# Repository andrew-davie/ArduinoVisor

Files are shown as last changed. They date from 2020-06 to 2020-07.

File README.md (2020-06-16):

# ArduinoVisor

Project/source files for Arduino Mechanical TV
Using ATMEGA32U4 processor (Arduino Micro)

For build log and instructions, see
https://www.taswegian.com/NBTV/forum/viewforum.php?f=28

Files are setup for Visual Studio Code project with PlatformIO installed.
Authors: Andrew Davie, Keith Colson

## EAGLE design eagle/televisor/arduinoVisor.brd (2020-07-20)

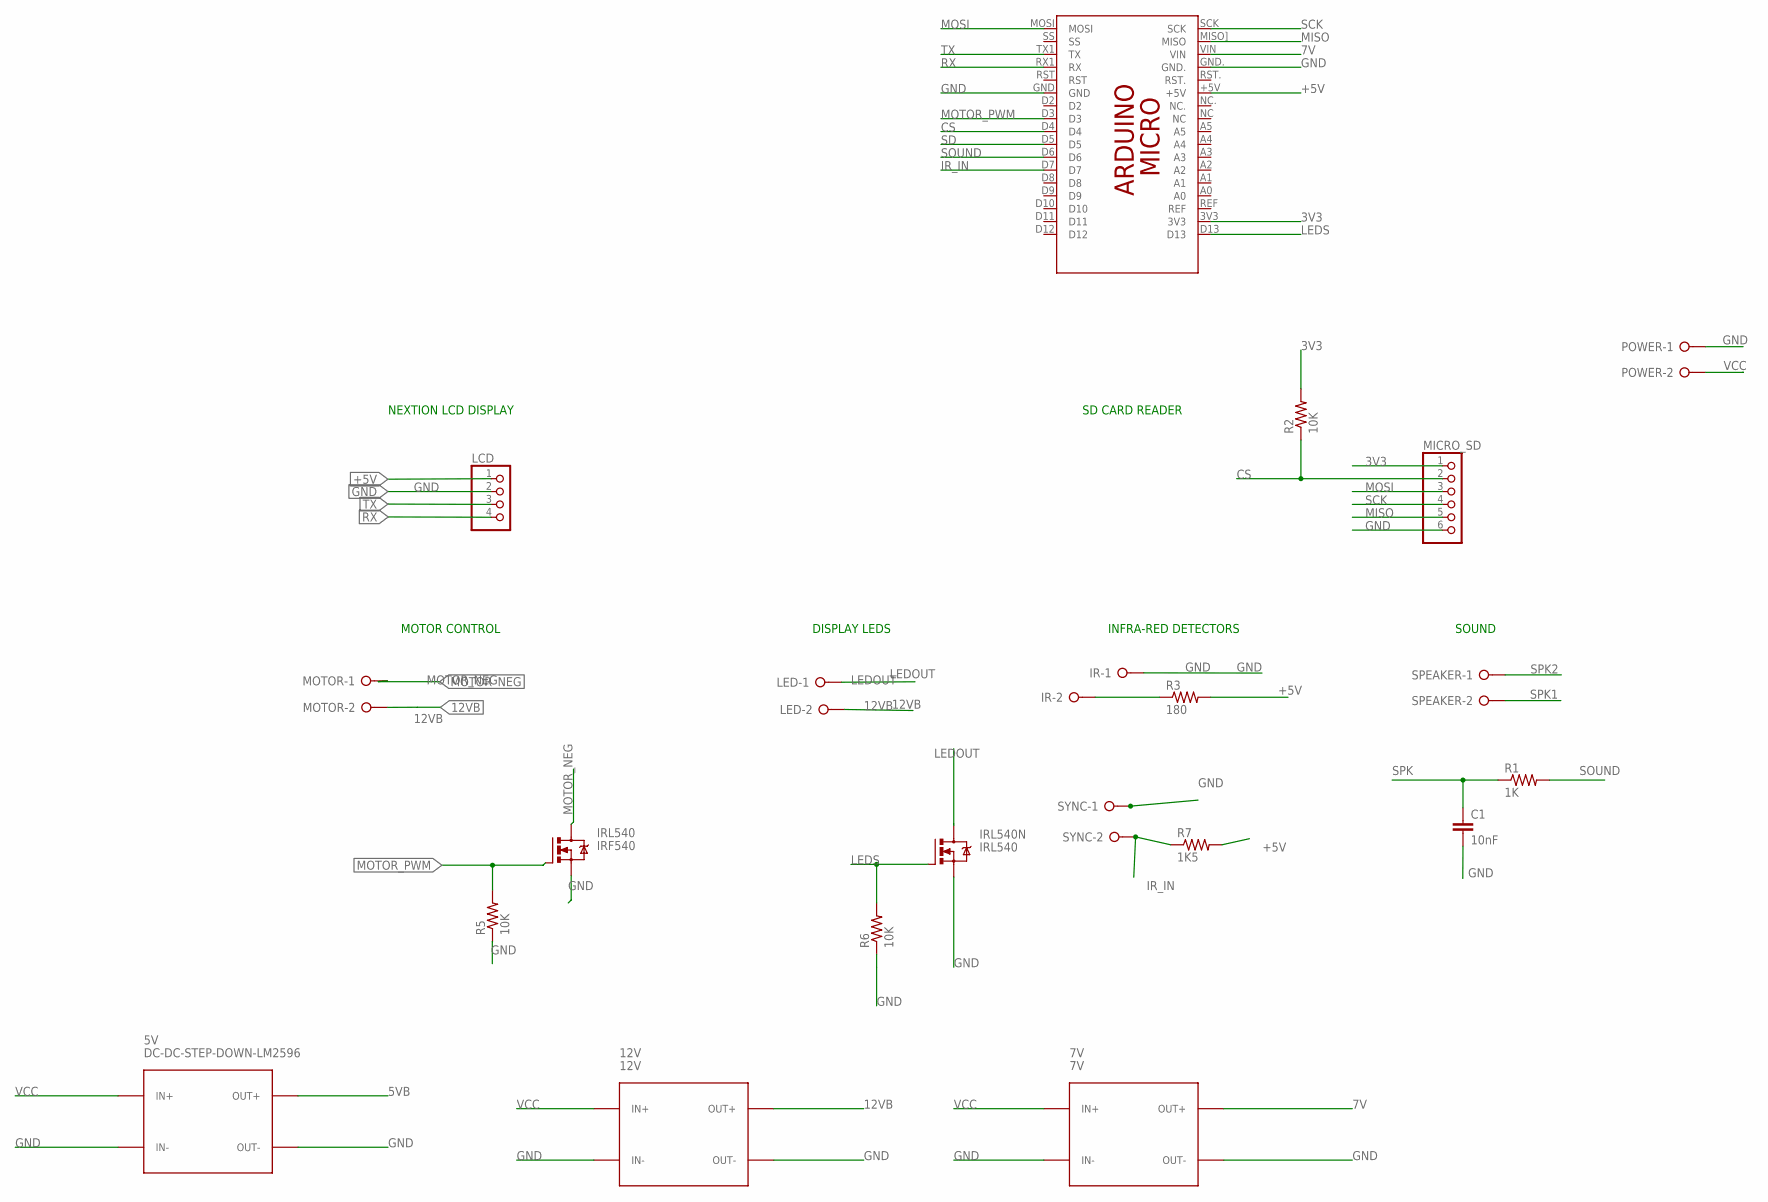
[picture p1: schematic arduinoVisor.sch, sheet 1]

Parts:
5V: DC-DC-STEP-DOWN-LM2596
7V: 7V; DC-DC-STEP-DOWN-LM2596
12V: 12V; DC-DC-STEP-DOWN-LM2596
C1: 10nF; C2.5-2
IR: W237-02P; W237-132
IRL540: IRF540; TO220BV
IRL540N: IRL540; TO220BV
LCD: PINHD-1X4; 1X04
LED: W237-02P; W237-132
MICRO_SD: PINHD-1X6; 1X06
MOTOR: W237-02P; W237-132
PCB2: ARDUINO_MICRO
POWER: W237-02P; W237-132
R1: 1K; 0207/10
R2, R5, R6: 10K; 0207/10
R3: 180; 0207/10
R7: 1K5; 0207/10
SPEAKER: W237-02P; W237-132
SYNC: W237-02P; W237-132

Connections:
3V3: MICRO_SD.1, PCB2.3V3, R2.2
5VB: 5V.OUT+; also elsewhere on the board
7V: 7V.OUT+, PCB2.VIN
12VB: 12V.OUT+, LED.2, MOTOR.2
+5V: LCD.1, PCB2.+5V, R3.2, R7.2
CS: MICRO_SD.2, PCB2.D4, R2.1
GND: 5V.IN-, 5V.OUT-, 7V.IN-, 7V.OUT-, 12V.IN-, 12V.OUT-, C1.2, IR.1, IRL540.S, IRL540N.S, LCD.2, MICRO_SD.6, PCB2.GND, PCB2.GND., POWER.1, R5.1, R6.1, SYNC.1; also elsewhere on the board
IR_IN: PCB2.D7, R7.1, SYNC.2
IR_OUT: IR.2, R3.1
LEDOUT: IRL540N.D, LED.1
LEDS: IRL540N.G, PCB2.D13, R6.2
MISO: MICRO_SD.5, PCB2.MISO] (MISO)
MOSI: MICRO_SD.3, PCB2.MOSI
MOTOR_NEG: IRL540.D, MOTOR.1
MOTOR_PWM: IRL540.G, PCB2.D3, R5.2
RX: LCD.4, PCB2.RX1 (RX)
SCK: MICRO_SD.4, PCB2.SCK
SD: PCB2.D5; also elsewhere on the board
SOUND: PCB2.D6, R1.2
SPK: C1.1, R1.1; also elsewhere on the board
SPK1: SPEAKER.2; also elsewhere on the board
SPK2: SPEAKER.1; also elsewhere on the board
TX: LCD.3, PCB2.TX1 (TX)
VCC: 5V.IN+, 7V.IN+, 12V.IN+, POWER.2

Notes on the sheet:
MOTOR CONTROL
DISPLAY LEDS
INFRA-RED DETECTORS
NEXTION LCD DISPLAY
SD CARD READER
SOUND

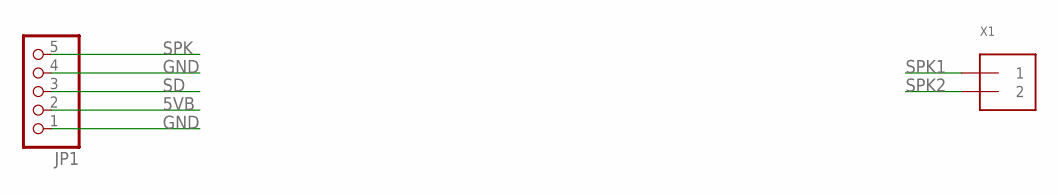
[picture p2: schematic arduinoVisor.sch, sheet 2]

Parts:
JP1: HEADER-1X570MIL; 1X05_ROUND_70
X1: TERMBLOCK_1X2; TERMBLOCK_1X2-3.5MM

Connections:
5VB: JP1.2; also elsewhere on the board
GND: JP1.1, JP1.4; also elsewhere on the board
SD: JP1.3; also elsewhere on the board
SPK: JP1.5; also elsewhere on the board
SPK1: X1.1; also elsewhere on the board
SPK2: X1.2; also elsewhere on the board

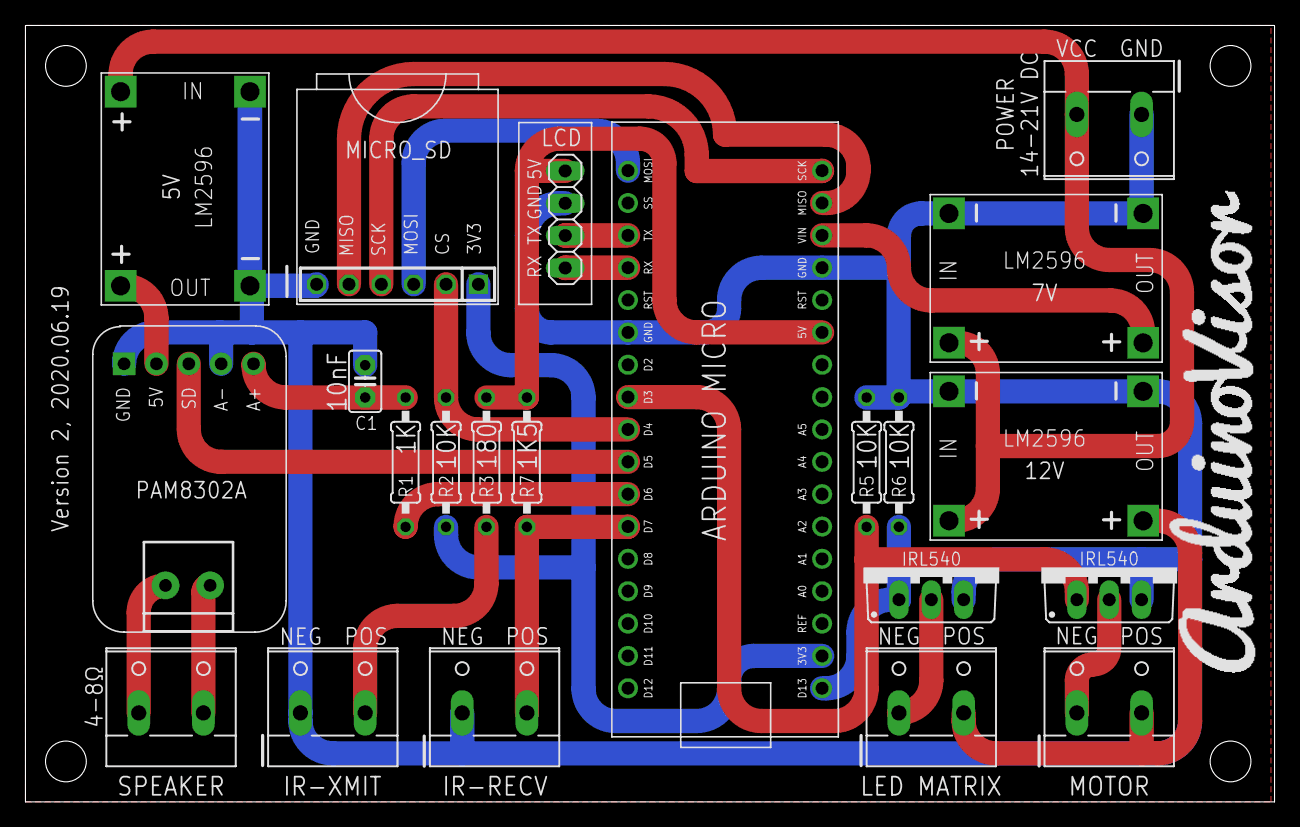
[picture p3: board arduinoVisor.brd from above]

Board: 2 copper layers, 98.1 x 61.0 mm, 23 parts (0 on the bottom side), 24 nets.

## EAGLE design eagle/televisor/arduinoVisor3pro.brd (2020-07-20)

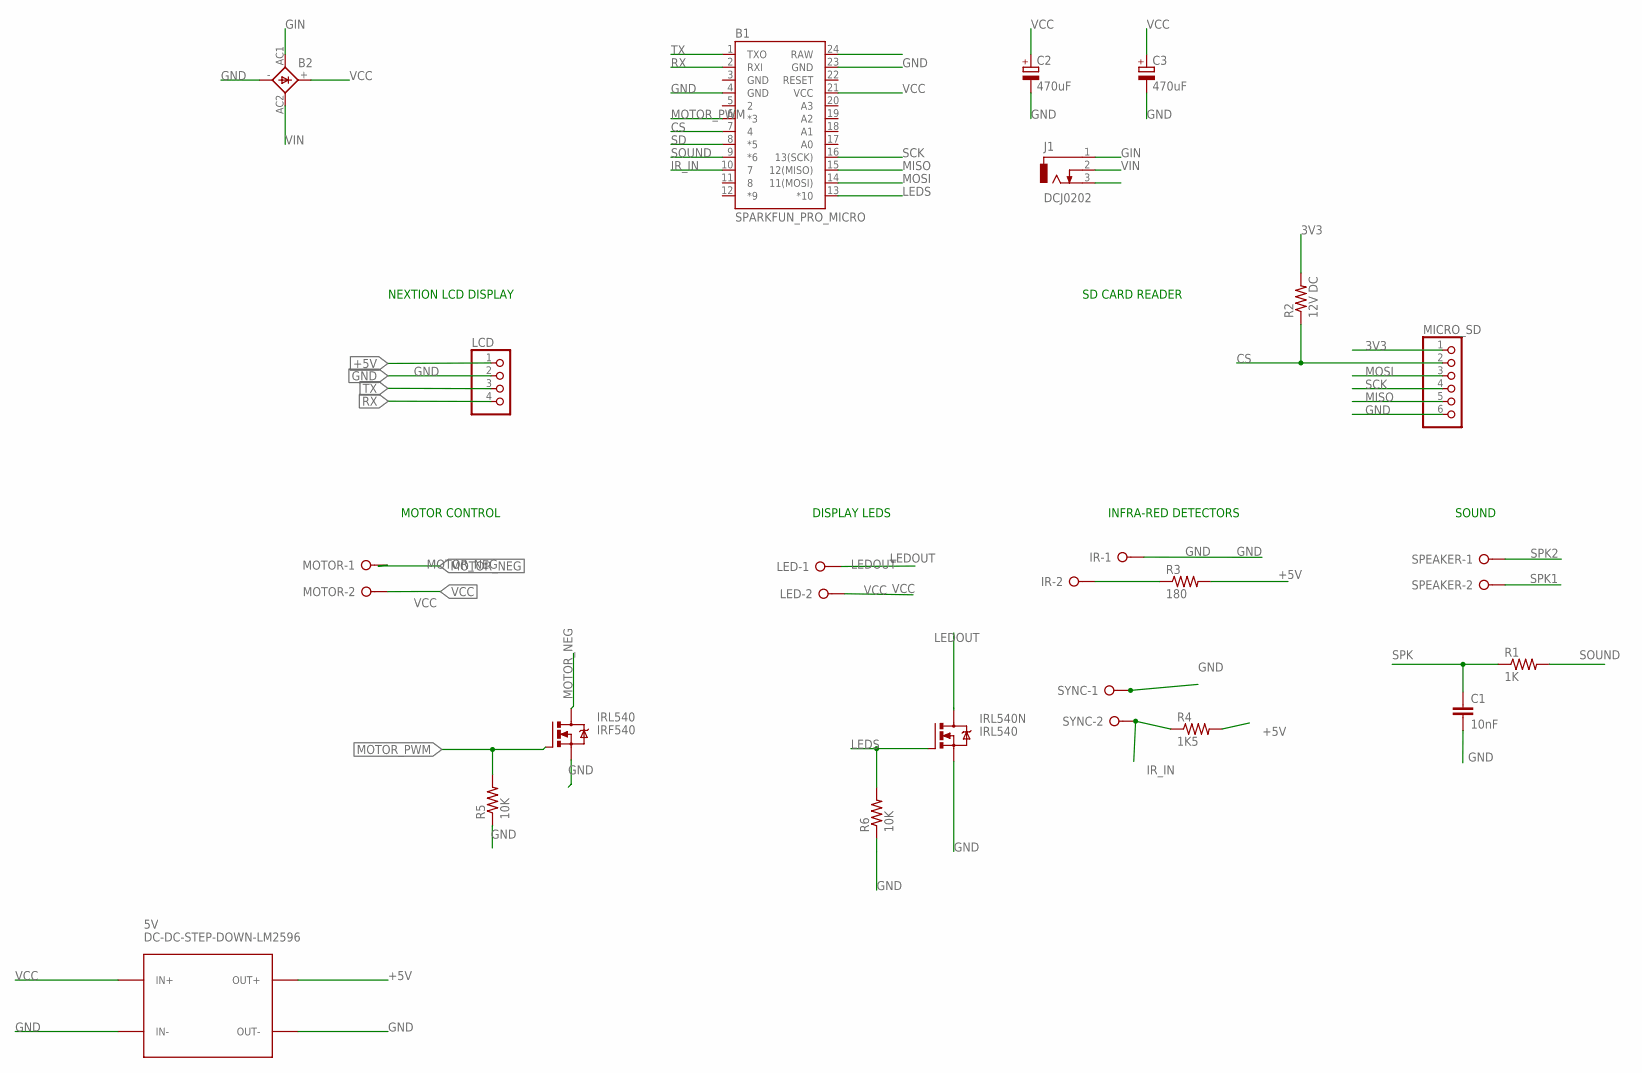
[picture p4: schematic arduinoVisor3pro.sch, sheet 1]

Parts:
5V: DC-DC-STEP-DOWN-LM2596
B1: SPARKFUN_PRO_MICRO
B2: 1KAB
C1: 10nF; C2.5-2
C2, C3: 470uF; E5-6
IR: W237-02P; W237-132
IRL540: IRF540; TO220BV
IRL540N: IRL540; TO220BV
J1: DCJ0202
LCD: PINHD-1X4; 1X04
LED: W237-02P; W237-132
MICRO_SD: PINHD-1X6; 1X06
MOTOR: W237-02P; W237-132
R1: 1K; 0207/10
R2: 12V DC; 0207/10
R3: 180; 0207/10
R4: 1K5; 0207/10
R5, R6: 10K; 0207/10
SPEAKER: W237-02P; W237-132
SYNC: W237-02P; W237-132

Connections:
3V3: MICRO_SD.1, R2.2
+5V: 5V.OUT+, B1.24 (RAW), LCD.1, R3.2, R4.2; also elsewhere on the board
CS: B1.7 (4), MICRO_SD.2, R2.1
GIN: B2.AC1, J1.1
GND: 5V.IN-, 5V.OUT-, B1.3 (GND), B1.4 (GND), B1.23 (GND), B2.-, C1.2, C2.-, C3.-, IR.1, IRL540.S, IRL540N.S, LCD.2, MICRO_SD.6, R5.1, R6.1, SYNC.1; also elsewhere on the board
IR_IN: B1.10 (7), R4.1, SYNC.2
IR_OUT: IR.2, R3.1
LEDOUT: IRL540N.D, LED.1
LEDS: B1.13 (*10), IRL540N.G, R6.2
MISO: B1.15 (12(MISO)), MICRO_SD.5
MOSI: B1.14 (11(MOSI)), MICRO_SD.3
MOTOR_NEG: IRL540.D, MOTOR.1
MOTOR_PWM: B1.6 (*3), IRL540.G, R5.2
RX: B1.2 (RXI), LCD.4
SCK: B1.16 (13(SCK)), MICRO_SD.4
SD: B1.8 (*5); also elsewhere on the board
SOUND: B1.9 (*6), R1.2
SPK: C1.1, R1.1; also elsewhere on the board
SPK1: SPEAKER.2; also elsewhere on the board
SPK2: SPEAKER.1; also elsewhere on the board
TX: B1.1 (TXO), LCD.3
VCC: 5V.IN+, B1.21 (VCC), B2.+, C2.+, C3.+, LED.2, MOTOR.2
VIN: B2.AC2, J1.2

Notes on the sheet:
MOTOR CONTROL
DISPLAY LEDS
INFRA-RED DETECTORS
NEXTION LCD DISPLAY
SD CARD READER
SOUND

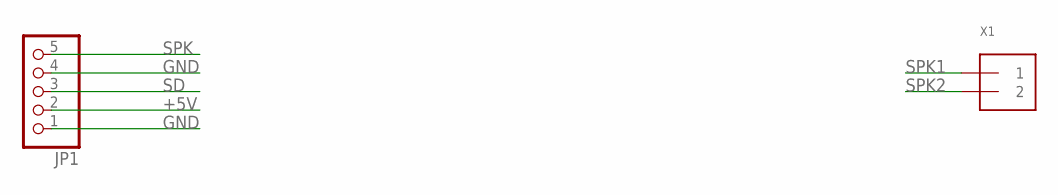
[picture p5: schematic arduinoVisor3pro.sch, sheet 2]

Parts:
JP1: HEADER-1X570MIL; 1X05_ROUND_70
X1: TERMBLOCK_1X2; TERMBLOCK_1X2-3.5MM

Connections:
+5V: JP1.2; also elsewhere on the board
GND: JP1.1, JP1.4; also elsewhere on the board
SD: JP1.3; also elsewhere on the board
SPK: JP1.5; also elsewhere on the board
SPK1: X1.1; also elsewhere on the board
SPK2: X1.2; also elsewhere on the board

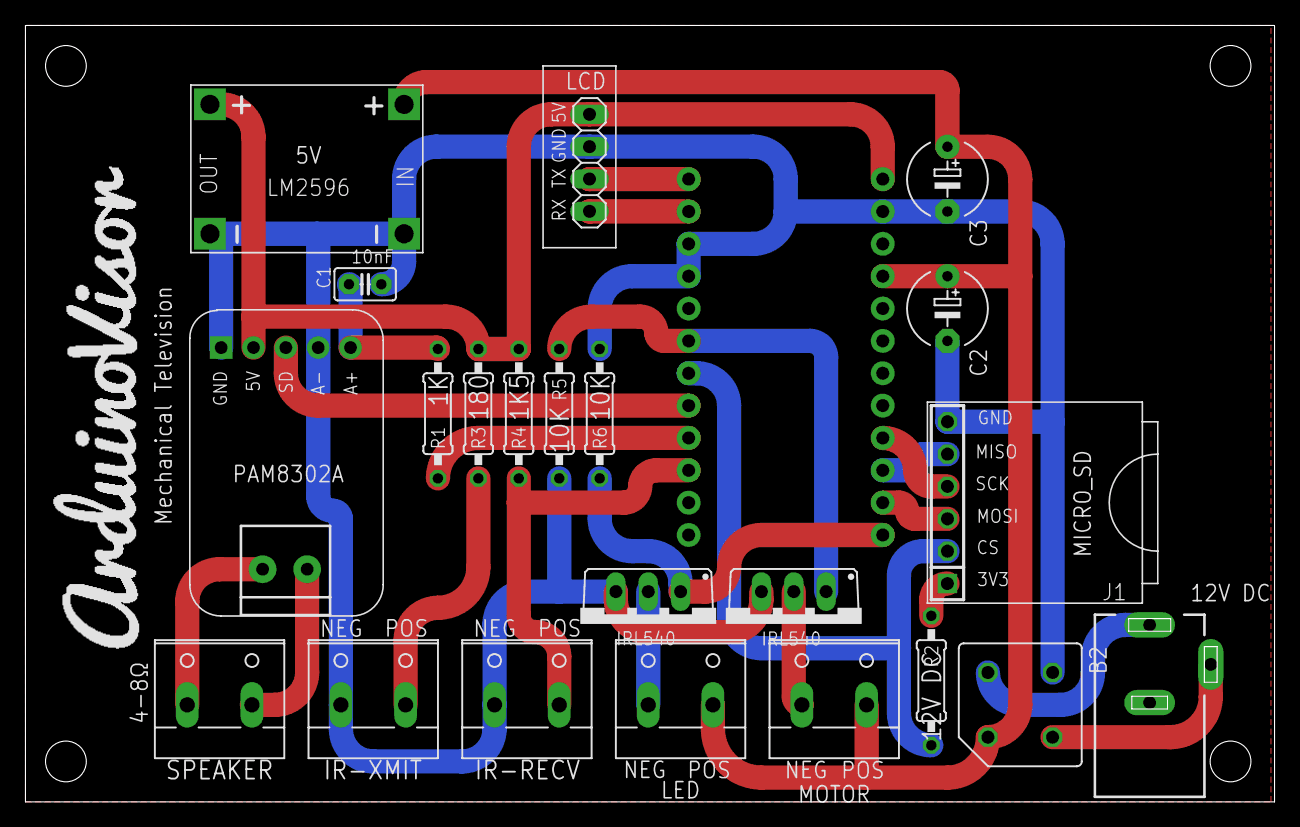
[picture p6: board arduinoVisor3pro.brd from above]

Board: 2 copper layers, 98.1 x 61.0 mm, 24 parts (0 on the bottom side), 23 nets.

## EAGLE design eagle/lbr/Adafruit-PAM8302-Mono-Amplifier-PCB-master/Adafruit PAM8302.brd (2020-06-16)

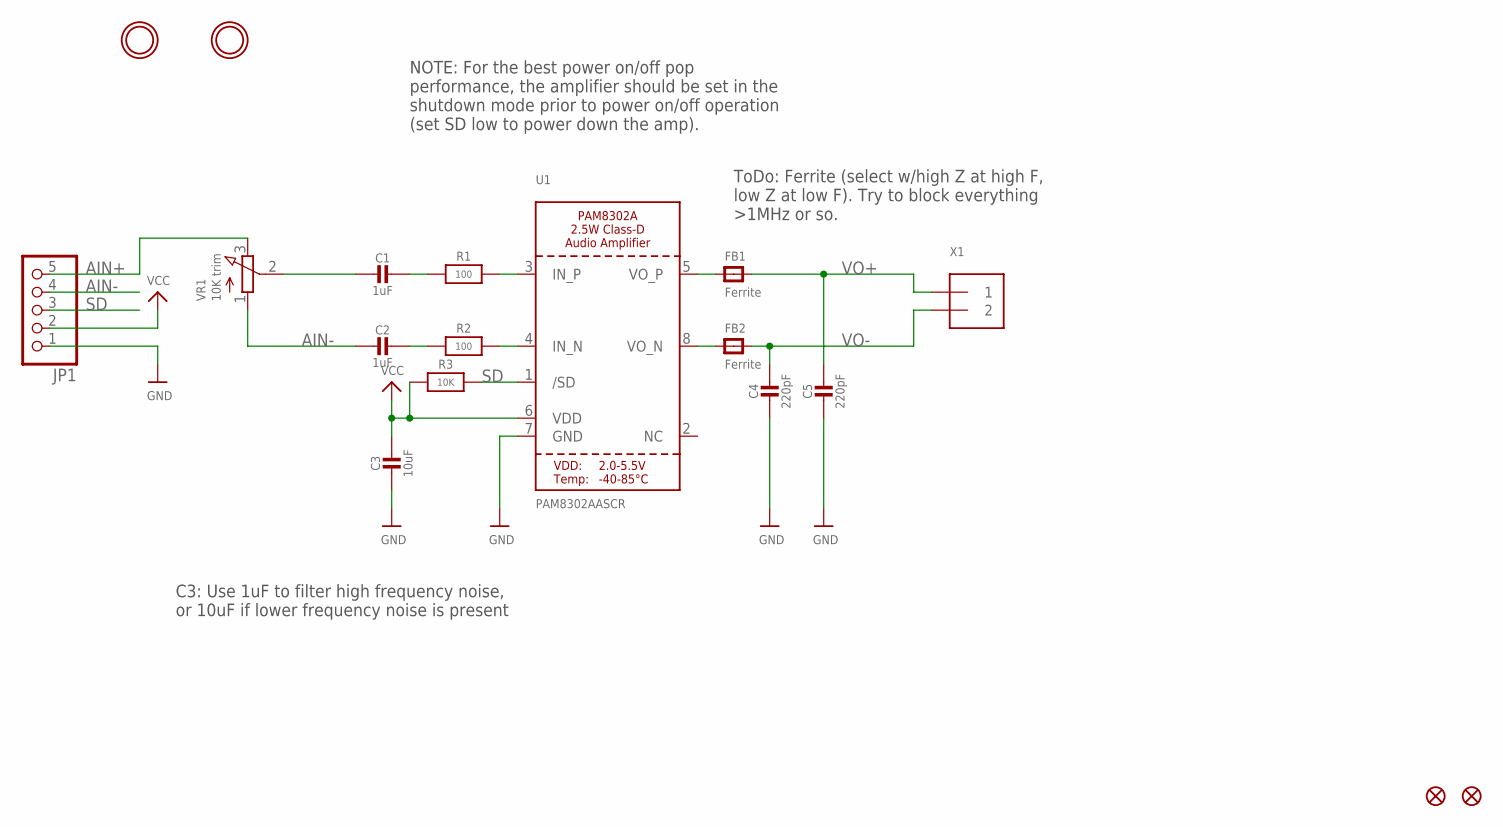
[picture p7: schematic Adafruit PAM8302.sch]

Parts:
C1, C2: 1uF; 0805-NO
C3: 10uF; 0805-NO
C4, C5: 220pF; 0805-NO
FB1, FB2: Ferrite; _0805
FID1, FID2: FIDUCIAL""; FIDUCIAL_1MM
JP1: HEADER-1X570MIL; 1X05_ROUND_70
R1, R2: 100; 0805-NO
R3: 10K; 0805-NO
U1: PAM8302AASCR; MSOP8_0.65MM
U$10, U$11: MOUNTINGHOLE2.0; MOUNTINGHOLE_2.0_PLATED
VR1: 10K trim; TRIMPOT_BOURNS_3303W
X1: TERMBLOCK_1X2; TERMBLOCK_1X2-3.5MM

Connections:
AIN+: JP1.5, VR1.3 (E)
AIN-: C2.2, JP1.4, VR1.1 (A)
GND: C3.2, C4.2, C5.2, JP1.1, U1.7 (GND)
unnamed: R2.2, U1.4 (IN_N)
unnamed: R1.2, U1.3 (IN_P)
unnamed: C1.1, R1.1
unnamed: C2.1, R2.1
unnamed: FB2.1, U1.8 (VO_N)
unnamed: FB1.1, U1.5 (VO_P)
unnamed: C1.2, VR1.2 (S)
SD: JP1.3, R3.2, U1.1 (/SD)
VCC: C3.1, JP1.2, R3.1, U1.6 (VDD)
VO+: C5.1, FB1.2, X1.1
VO-: C4.1, FB2.2, X1.2

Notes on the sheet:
ToDo: Ferrite (select w/high Z at high F, low Z at low F). Try to block everything >1MHz or so.
C3: Use 1uF to filter high frequency noise, or 10uF if lower frequency noise is present
NOTE: For the best power on/off pop performance, the amplifier should be set in the shutdown mode prior to power on/off operation (set SD low to power down the amp).

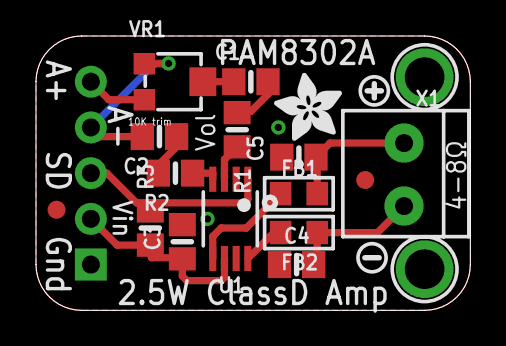
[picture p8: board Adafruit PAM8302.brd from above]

Board: 2 copper layers, 24.1 x 15.2 mm, 22 parts (1 on the bottom side), 14 nets.

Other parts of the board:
U$3: SYMBOL_PLUS
U$4: SYMBOL_MINUS
U$5: ADAFRUIT_3.5MM
U$6: PCBFEAT-REV-040

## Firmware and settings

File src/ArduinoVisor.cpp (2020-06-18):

////////////////////////////////////////////////////////////////////////////////////////////////////////////////////////////////
// Arduino Mechanical Televisor  https://github.com/andrew-davie/NBTV                                                         //
// This program implements all the functions needed for a working mechanical televisor using an a                             //
// Arduino Micro. For more information see https://www.taswegian.com/NBTV/forum/viewforum.php?f=28                            //
//                                                                                                                            //
// program by Andrew Davie (andrew@taswegian.com), March 2017...                                                              //
// and Keith Colson - http://www.edns.co.nz/index.php/about/ - September 2017...                                               //
//                                                                                                                            //
// Notes:                                                                                                                     //
// 1. Strings in the code actually use RAM.  To save RAM, use the macro F("string")                                           //
// 2. >>>> Debug mode is entered by sending a character on the console within two seconds of startup <<<<                     //
// 3. using 70% ram or more can make the upload fail, hold the reset button down and release when upload starts to fix it     //
//                                                                                                                            //
////////////////////////////////////////////////////////////////////////////////////////////////////////////////////////////////

#include <Arduino.h>
#include "televisor.h" // the main header file

void stopButtonCallback();

void fixVideoTable();

void fixAudioTable(uint8_t customVolume);

byte calculatePI(double speedErr, double frameErr);

// *************************** Nextion Library Support (touch screen) *********************************************************
#include "nexlite.h" // file to get rid of nextion library

///////////////////////////////////////////////////////////////////////////////////////////////////////////////////////////////
bool playing = false;
bool showInfo; // info txt file present
bool debug = false;
bool nextion = false; // assume no nextion connected until found
bool forceTimePreventSeeker;

uint8_t uiMode;        // = MODE_TITLE_INIT;     // program state
uint8_t selection = 0; // selected track # from menu
uint8_t baseVal;
uint32_t lastSeekPosition;

uint32_t shiftFrame = 80;

// *************************** Global Variables ***************************************************************

// PID variables
double integral;
double lastTime; // this is used to calculate delta time
double lastErr;  // this is used to calculate delta error
double motorSpeed;

File nbtv;
SdFat nbtvSD;

////////////////////////////////////////////////////////////////////////////////////////////////////////////////////////////////

uint8_t video[VIDEO_SIZE]; // convert sample to modified brightness/contrast/gamma/bit depth
uint8_t audio[AUDIO_SIZE]; // convert sample to modified audio/bit depth

int16_t customBrightness;
long customContrast2; // a X.Y fractional  (8 bit fractions) so 256 = 1.0f   and 512 = 2.0f

uint8_t customGamma; // flags if gamma should be applied

////////////////////////////////////////////////////////////////////////////////////////////////////////////////////////////////

uint32_t customRepeat = 0;

uint8_t countFiles(void);

void resetStream(long seeker);

void setupFastPwm(int mode);

void setupMotorPWM();

void qInit(char *name);

void drawTime(const char *name, int sec);

void composeMenuItem(int item, int s, char *p, bool hunt);

uint8_t circularAudioVideoBuffer[CIRCULAR_BUFFER_SIZE];

uint32_t playbackAbsolute;
uint32_t lastPlaybackAbsolute;
uint32_t dataPosition; // WAV file start of data chunk (for rewind/seek positioning)

uint8_t *pbp;

uint32_t videoLength;
uint32_t streamAbsolute;
uint16_t bufferOffset;
uint16_t sampleRate;
uint16_t singleFrame;
uint8_t bytesPerSample; // bytes per sample
uint32_t oneSecond;

unsigned long lastDetectedIR;

////////////////////////////////////////////////////////////////////////////////////////////////////////////////////////////////
void nl_Callback(struct nl_struct *ns)
{
    // event from nextion - nl means nextion lite - ns means nextion struct
    // Serial.print(ns->buff[1]);  Serial.print("  ,  "); Serial.print(ns->buff[2]); Serial.print("  ,  "); Serial.println(ns->buff[3]);//  Serial.println(ns->buff[4]);
    switch (ns->buff[0]) {
        // command type
        case NEX_RET_EVENT_TOUCH_HEAD: // touch happened       0x65 0x02 0x08 0x00 0xFF 0xFF 0xFF
            gotTouch(ns);          // call the touch parser
            break;

        case NEX_RET_NUMBER_HEAD: // get ?.val result     0x71 0x80 0x00 0x00 0x00 0xFF 0xFF 0xFF
            gotValue(ns);     // call the number parser
            break;

        case NEX_RET_CMD_FINISHED: // basically an ACK     0x01 0xFF 0xFF 0xFF
            break;             // nothing needed here
    }
}

void titleCallback();

void gotTouch(struct nl_struct *ns)
{

    switch (ns->buff[1]) {
        // page number

        case PAGE_STRT: // page 0 has touch
            titleCallback();
            break;

        case PAGE_MENU: // page 1 has touch
            switch (ns->buff[2]) {
                // id
                case H0_ID: // file slider touch
                    // nl_GetVal(H0_GET, H0_NAME);   // get file list slide value
                    nl_GetVal(BAS_GET, BAS_NAME); // get the base value (scroll position)
                    break;

                case FIL_ID:              // file selected
                    nl_GetVal(FIL_GET, FIL_NAME); // get file to open slide value
                    break;
            }

            break;

        case PAGE_PLAY: // page 2 has touch
            switch (ns->buff[2]) {
                // id
                case BRT_ID:              // brightness slider touch
                    nl_GetVal(BRT_GET, BRT_NAME); // get brightness slide value
                    break;

                case CON_ID:              // contrast slider touch
                    nl_GetVal(CON_GET, CON_NAME); // get contrast slide value
                    break;

                case VOL_ID:              // 0x71 0x80 0x00 0x00 0x00 0xFF 0xFF 0xFF
                    nl_GetVal(VOL_GET, VOL_NAME); // get volume slide value
                    break;

                case SEK_ID:              // seeker slider touch
                    nl_GetVal(SEK_GET, SEK_NAME); // get seeker slide value
                    break;

                case INF_ID: // info button touch down

                    if (showInfo) {
                        nl_SetPage(PAGE_INFO); // show info page
                        uiMode = MODE_INFO_SCREEN; // set mode as info page
                    }

                    break;

                case SHF_ID:       // shift button touch down
                    nl_SetPage(PAGE_SHFT); // show shift page
                    uiMode = MODE_SHIFTER;
                    break;

                case GAM_ID:              // gamma button touch down
                    nl_GetVal(GAM_GET, GAM_NAME); // get gamma button value
                    break;

                case REP_ID:
                    nl_GetVal(REP_GET, REP_NAME); // get repeat button value
                    break;

                case STP_ID: // stop button touch down
                    stopButtonCallback();
                    break;
            }

            break;

        case PAGE_SHFT: // Shifter page 3 event
            switch (ns->buff[2]) {
                // id
                case OKY_ID: // okay button to exit this screen
                    nl_SetPage(PAGE_PLAY);
                    uiMode = MODE_PLAY;
                    playing = true;
                    break;

                case ADJ_ID: // adjust button 10 bU up, 11 bL left, 12 bD down, 13 bR right
                    // can get x here and get y in the response to x arriving
                    nl_GetVal(XPO_GET, XPO_NAME); // get x shift value
                    // nl_GetVal(YPO_GET,YPO_GET); // get y shift value
                    break;
            }

            break;

        case PAGE_INFO:        // Info page 4 touch event
            nl_SetPage(PAGE_PLAY); // Go back to the play screen
            break;
    }
}

void gotValue(struct nl_struct *ns)
{
    // 0x71 0x80 0x00 0x00 0x00 0xFF 0xFF 0xFF
    // Serial.print("prevId = ");Serial.write(ns->prevId);Serial.print(", val = ");Serial.println(ns->buff[1]);
    switch (ns->prevId) {
        case BRT_NAME:                          // value of brightness control slider
            customBrightness = (ns->buff[1] - 128); // << 1;
            fixVideoTable();
            break;

        case CON_NAME:                     // value of contrast control slider
            customContrast2 = ns->buff[1] * 2; // Serial.print("Contraat Val = "); Serial.println(ns->buff[1]);
            fixVideoTable();
            break;

        case VOL_NAME: // value of volume control slider
            fixAudioTable(ns->buff[1]);
            break;

        case GAM_NAME: // gamma toggle button value
            customGamma = ns->buff[1];
            fixVideoTable();
            break;

        case REP_NAME: // repeat toggle button value
            customRepeat = ns->buff[1];
            break;

        case SEK_NAME: // value of seeker control slider
            uint32_t seekPos;
            seekPos = (long)(((double)ns->buff[1] / 255.) * ((double)videoLength / singleFrame));
            resetStream(seekPos * singleFrame);
            forceTimePreventSeeker = true; // draw the time but not the seeker bar
            break;

        case FIL_NAME:           // value of file selected
            selection = ns->buff[1]; // track selected
            commenceSelectedTrack(true);
            break;

        case BAS_NAME: // got the base position of the file scroll list
            baseVal = ns->buff[1];
            nl_GetVal(RQU_GET, RQU_NAME); // what kind of update needs doing to the file list screen?
            break;

        case RQU_NAME: // file list needs updating
            writeMenuStrings(baseVal, ns->buff[1]);
            break;

        case XPO_NAME: // value of shifter x position
            Serial.print("shifter x = ");
            Serial.println(ns->buff[1]);
            // shiftFrame = ns->buff[1];
            // NexVariable shift = NexVariable(3, 1, "s");
            // shift.getValue(&shiftFrame);
            nl_GetVal(YPO_GET, YPO_NAME); // get y shift value
            break;

        case YPO_NAME: // value of shifter x position
            Serial.print("shifter y = ");
            Serial.println(ns->buff[1]);
            // shiftFrame = ns->buff[1];
            // NexVariable shift = NexVariable(3, 1, "s");
            // shift.getValue(&shiftFrame);
            break;

        case 9: //  what was this? maybe the file scroll bar?
            Serial.print("wtf = ");
            Serial.println(ns->buff[1]);
            break;
    }
}

void fixVideoTable()
{
    for (int i = 0; i < VIDEO_SIZE; i++) {

        long val = (i << VIDEO_SHIFT) * customContrast2;
        val >>= 8;
        val += customBrightness;

        if (val < 0)
            val = 0;

        if (val > 255)
            val = 255;

        if (customGamma)
            val = pgm_read_byte(&gamma8[val]); // for now we have kept the gamma table

        video[i] = val;
    }
}

void fixAudioTable(uint8_t customVolume)
{
    uint8_t logVolume = pgm_read_byte(&gamma8[customVolume]);

    for (int i = 0; i < AUDIO_SIZE; i++)
        audio[i] = (((int)((i << AUDIO_SHIFT) - 0x80)) * logVolume + 0x8000) >> 8;
}

////////////////////////////////////////////////////////////////////////////////////////////////////////////////////////////////
// Data playback interrupt
// This is an interrupt that runs at the frequency of the WAV file data (i.e, 22050Hz, 44100Hz, ...)
// It takes data from the circular buffer 'circularAudioVideoBuffer' and sends it to the LED array
// and to the speaker.

#ifndef STUFFROMLOOP
    bool alreadyStreaming = false;
#endif

ISR(TIMER3_OVF_vect)
{

    OCR4A = video[*pbp++
                  #if VIDEO_SHIFT > 0
                      >> VIDEO_SHIFT
                  #endif
            ];

    TCCR4A = 0x82;

    // Write the audio to pin 6 PWM duty cycle
    OCR4D = audio[*pbp++
                  #if AUDIO_SHIFT > 0
                      >> AUDIO_SHIFT
                  #endif
            ];

    DDRD |= 0x80;
    TCCR4C |= 0x09;

    playbackAbsolute += bytesPerSample;

    if (pbp >= circularAudioVideoBuffer + CIRCULAR_BUFFER_SIZE)
        pbp = circularAudioVideoBuffer;

    #ifdef STUFFROMLOOP // stuffing from loop and this runs 8.4khz round robin
}

void stuffer()
{
    #endif

    // This code tries to fill up the unused part(s) of the circular buffer that contains the streaming
    // audio & video from the WAV file being played. 'bufferOffset' is the location of the next buffer
    // write, and this wraps when it gets to the end of the buffer. The number of bytes to write is
    // calculated from two playback pointers - 'playbackAbsolute' which is the current position in the
    // audio/video stream that's ACTUALLY being shown/heard, and 'streamAbsolute' which is the position
    // of the actually streamed data (less 1 actual buffer length, as it's pre-read at the start). Those
    // give us a way to calculate the amount of free bytes ('bytesToStream') which need to be filled by
    // reading data from the SD card. Note that 'playbackPointer' can (and will!) change while this
    // routine is streaming data from the SD.  The hope is that we can read data from the SD to the buffer
    // fast enough to keep the playback happy. If we can't - then we get glitches on the screen/audio

    #ifndef STUFFROMLOOP

        if (!alreadyStreaming) {
            alreadyStreaming = true; // prevent THIS *part of the code* from interrupting itself...
            sei();               // allow interrupt again
    #endif

    uint32_t bytesToStream = playbackAbsolute - streamAbsolute;

    if (bytesToStream > 63) {
        // might be more efficient reading larger blocks!

        void *dest = (void *)(circularAudioVideoBuffer + bufferOffset);
        bufferOffset += bytesToStream;

        if (bufferOffset >= CIRCULAR_BUFFER_SIZE) {
            bytesToStream = CIRCULAR_BUFFER_SIZE - bufferOffset + bytesToStream;
            bufferOffset = 0;
        }

        nbtv.read(dest, bytesToStream);
        streamAbsolute += bytesToStream;
    }

    #ifndef STUFFROMLOOP
        alreadyStreaming = false;
}

    #endif
}

// -- Analog comparator interrupt service routine -------------------------------------------------
// Triggered by sync hole detected by IR sensor, connected to pin 7 (AC)

ISR(ANALOG_COMP_vect)
{
    // Serial.println(F("IR"));
    uint32_t irAbsolute = playbackAbsolute;

    double deltaSample = irAbsolute - lastDetectedIR;

    // Serial.println(deltaSample); always = 3072 to 3074 when synced

    if (deltaSample < 1000) // debounce or stopped
        return;

    // should really off load all the calcs to main and keep this super lean
    lastDetectedIR = irAbsolute; // store for use on next cycle

    // This next bit is super cool.  The PID synchronises the disc speed to 12.5 Hz (indirectly through the singleFrame
    // value, which is a count of #samples per rotation at 12.5 Hz).  Since the disc and the playback of the video
    // are supposed to be exactly in synch, we know that both SHOULD start a frame/rotation at exactly the same time.
    // So since we know we're at the start of a rotation (we just detected the synch hole), then we can compare
    // how 'out of phase' the video is by simply looking at the video playback sample # ('plabackAbsolute') and
    // use the sub-frame offset as an indicator of how inaccurate the framing is.  Once we know that, instead of
    // trying to change the video timing, we just change the disc speed. How do we do that?  By tricking the PID
    // into thinking the disc is running slower than it really is by telling it that the time between now and
    // the last detected rotation is actually longer than measured. A consequence of this is that the PID will try
    // to speed the disc up a fraction, which will in turn mean the video is playing slightly slower relative
    // to the timing of the disc, and the image will shift left and up.  We also (gosh this is elegant) get the
    // ability to shift the image up/down.  So we can hardwire the exact framing vertical of the displayed image,
    // too.

    int32_t pbDelta = irAbsolute % singleFrame; // how inaccurate is framing?

    if (pbDelta >= singleFrame / 2)         // its faster to re frame in the other direction
        pbDelta = -(singleFrame - pbDelta); // this needs to be a negative number to get the other direction

    // Serial.println(pbDelta);  // max about 3100 nominal about 75 shiftFrame = 75 so thats the matching number!

#define P_BODGE 0 /*7 for keith*/

    double sError = (deltaSample - (3072 - P_BODGE)); // spead error - proportional with target of 3072 - bodge to get P perfectly balanced
    double fError = (pbDelta - 75 /*+ 40*/);          // frame error

    byte pidx = calculatePI(sError, fError); // write the new motor PI speed

    if (pidx > 0) // if it is a good return value
        // Serial.println(pidx);
        OCR0B = pidx; // set motor pwm value

    #ifdef DEBUG_PIISR
        digitalWrite(DEBUG_PIN, LOW); // round robin speed
    #endif
}

// PID (from http://brettbeauregard.com/blog/2011/04/improving-the-beginners-pid-introduction/)
byte calculatePI(double speedErr, double frameErr)
{
    // pass in error

    double now = ((double)playbackAbsolute) / singleFrame;
    double timeChange = now - lastTime;
    double proportional;
    float motorPWM;

    if (lastTime == 0) {
        // avoids glitch on first round
        lastTime = now;
        return 0; // return zero for error (no motor action will be taken)
    }

    proportional = KP_SPEED * speedErr; // do this multiplication just once

    integral += (frameErr * timeChange); // this is the integral value

    if (speedErr > LARGE_SPEED_ERR) // if speed error is large then turn off integral
        integral = 0;               // reset the integral

    if (speedErr < MAX_FRAME_ERR)                            // if speed error is small then tune the frame
        proportional = proportional + (frameErr * KP_FRAME); // this is how aggressive it hunts the frame edge

    motorPWM = (proportional + (KI_SPEED * integral)) + 0.5;

    if (motorPWM > MOT_PWM_MAX) // limit pwm to avoid overcurrent
        motorPWM = MOT_PWM_MAX;

    if (motorPWM < 1) // if smaller than 1
        motorPWM = 1; // return 1 for no error

    lastErr = speedErr; // store globals for next round
    lastTime = now;
    return (uint8_t)motorPWM;
}
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
void loop()
{

    if (nextion)
        nl_Listen(); // read nextion!

    if (playing) {

        #ifdef DEBUG_ROUNDRROBIN
            digitalWrite(DEBUG_PIN, HIGH); // round robin speed
        #endif

        #ifdef STUFFROMLOOP
            stuffer(); // these is a better place to call this as it should happen when info screen is shown while playing etc
        #endif     // this will do for testing

        #ifdef DEBUG_ROUNDRROBIN
            digitalWrite(DEBUG_PIN, LOW); // 4.5Khz ISR mode, STUFFROMLOOP 8.4Khz
        #endif

        // Display elapsed time in format MM:SS
        if (nextion) {
            if (forceTimePreventSeeker || playbackAbsolute - lastPlaybackAbsolute >= oneSecond) {
                // only update if > 1 second difference
                lastPlaybackAbsolute = playbackAbsolute;

                #ifdef DEBUG_BUFFERSIZE
                    Serial.println(playbackAbsolute - streamAbsolute); // this will be broken since the merge
                #endif

                drawTime("timePos", playbackAbsolute / oneSecond);

                if (!forceTimePreventSeeker) {

                    // Adjust the seekbar position to the current playback position
                    uint32_t seekPosition = 256. * playbackAbsolute / videoLength;

                    // uint32_t seekPosition = ( playbackAbsolute << 8 ) / videoLength;
                    if (seekPosition != lastSeekPosition) {
                        lastSeekPosition = seekPosition;
                        char cmd[] = "s.val=XXX";
                        utoa(seekPosition, cmd + 6, 10);
                        nl_SendCommand2(cmd);
                    }
                }

                forceTimePreventSeeker = false;
            }
        }

        handleEndOfVideo(MODE_PLAY);
    }
    else

        switch (uiMode) {

            case MODE_TITLE_INIT:

                if (nextion) {
                    nl_SendCommand2("bkcmd=2"); // TODO: not needed?
                    nl_SendCommand2("page 0");
                }

                uiMode = MODE_TITLE;
                break;

            case MODE_INIT:
                setupIRComparator(); // enables the comparator
                uiMode = MODE_SELECT_TRACK;
                break;

            case MODE_SELECT_TRACK: // file selection from menu

                if (!nextion) {
                    selection = 0;
                    commenceSelectedTrack(true);
                    customRepeat = true; // in this case, play all tracks and repeat
                }

                break;
        }
}

// EOF

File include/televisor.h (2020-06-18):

#ifndef _TELEVISOR_
#define _TELEVISOR_

// *************************** Optimisation and Debug *************************************************************************
#define  STUFFROMLOOP               // Stuff the buffer from main loop and not the interrupt
// #define  DEBUG_PLAYISR            // See how long the play isr takes, cannot use this at 44k
// #define  DEBUG_PIISR              // See how long the PI isr takes
// #define  DEBUG_ROUNDRROBIN        // See how fast the round robin is and how long the stuffer takes
// #define AUDIO_ONLY                // turns of the motor so you can test audio
// #define DEBUG_BUFFERSIZE          // shows how many bytes are being per block e.g. small numbers are good, use the serial plotter

// *************************** Arduino Library Support ************************************************************************
#include <Arduino.h>
// #define ROM const char PROGMEM /* adding progmem kills the string, why? */
#define ROM const char           /* need to work this out as ram usage drops 1774-1620=154 bytes! */

// *************************** SD Card Library Support ************************************************************************
#include <SdFat.h>
// Uses the SdFat Library at https://github.com/greiman/SdFat
// backup at http://www.taswegian.com/SdFat-master.zip

// *************************** Hardware details and settings  *****************************************************************
// Arduino pinout/connections:  https://www.taswegian.com/NBTV/forum/viewtopic.php?f=28&t=2298
//                              Pname  Description
#define PIN_MOTOR        3   /* D3     Motor PWM Pin D3 */
#define SD_CS_PIN        4   /* D4     Chip select for SD card */
#define PIN_SOUND_ENABLE 5   /* D5     Enable sudio amp when high */
//                           /* D7     IR_IN, opto sensor - Analog comparator */
#define DEBUG_PIN       12   /* D12    Used for scoping performance */
// LED_BUILTIN           ??   /* D??    Built in red led, already defined by arduino.h */
// digitalWrite(DEBUG_PIN, HIGH);
//                           /* D13    Led PWM - PWM from TIMER4 */
// SD Card Clock             /* SCK    SD card uses this pin */
// SD Card Master In         /* MISO   SD card uses this pin */
// SD Card Master Out        /* MOSI   SD card uses this pin */
// To Nextion RX pin         /* TX1    Send serial to Nextion */
// To Nextion TX pin         /* RX1    Get serial from Nextion */

// Special pin defines
#define PWM187k 1   // 187500 Hz pwm frequency for TIMER4 on pin */

// *************************** CONFIGURATION... *******************************************************************************
#define SD_BLOCK_SIZE    63         // 64 is worse at high speed ,if many bytes are need to be loaded in the buffer how many bytes do we max it to?
// #define OVERRIDE_SPEED
// #define OVERRIDE_VALUE   25000
#define CIRCULAR_BUFFER_SIZE 256    /* must be a multiple of sample size, I think its the power of e.g. 128 256 512 245=14% of ram */
// (i.e, (video+audio)*bytes per)) = 4 for 16-bit, and 2 for 8-bit

// *************************** Functio0n prototypes ***************************************************************************
void commenceSelectedTrack(bool);

void writeMenuStrings(uint8_t base, uint8_t updateReq);

// *************************** Tunings PID Motor speed and sync ***************************************************************
#define KP_SPEED          1.0F      /* Speed proportional - this is how agressivly it moves towards and out of sycn frame - vertical */
#define KP_FRAME          0.2F      /* Frame proportional - this is how agressivly it moves towards and out of sycn frame - horizontal */
#define KI_SPEED          0.01F     /* Speed integral - slow/long term speed stability */
#define MAX_FRAME_ERR    50         /* if the PID error is smaller than this then frame locking will commence */
#define LARGE_SPEED_ERR  50         /* if speed error is large then turn off I (integral) */
#define MOT_PWM_MAX     150         // can set this lower to stop smaller power supploes tripping

// states - add proper state machine
// buttons can be signals that run with in states
// use enum here?
#define MODE_INIT             0
#define MODE_TITLE            1
#define MODE_TITLE_INIT       2
#define MODE_SELECT_TRACK     3
#define MODE_PLAY             4
#define MODE_SHIFTER          5
#define MODE_INFO_SCREEN      6

// *************************** Nextion "custom" defines  *********************************************************************
void gotTouch (struct nl_struct *ns);

void gotValue (struct nl_struct *ns);

#define PAGE_STRT     0              /* page 0 start up screen */
#define PAGE_MENU     1              /* page 1 select file */
#define PAGE_PLAY     2              /* page 2 playing screen */
#define PAGE_SHFT     3              /* page 3 shift */
#define PAGE_INFO     4              /* page 4 show info */

// page 1 events
#define H0_ID        11             /* seeker slider */
// #define H0_NAME     'h'
// ROM     H0_GET[] = {"h0"};

#define FIL_ID       1              /* file selected touch */
#define FIL_NAME    'f'             /* used to get the id of which file was selected */
ROM FIL_GET[] = {"si"};

#define BAS_ID       14             /* base value for menu list */
#define BAS_NAME    'B'
ROM BAS_GET[] = {"bx"};

#define RQU_ID       15             /* required update value for menu list */
#define RQU_NAME    'R'
ROM RQU_GET[] = {"ru"};

// page 2 events
#define BRT_ID       5              /* brightness slider */
#define BRT_NAME    'b'
ROM BRT_GET[] = {"b"};

#define CON_ID       7              /* contrast slider */
#define CON_NAME    'c'
ROM CON_GET[] = {"c"};

#define VOL_ID       8              /* volume slider */
#define VOL_NAME    'v'
ROM VOL_GET[] = {"v"};

#define SEK_ID       21             /* seeker slider */
#define SEK_NAME    's'
ROM SEK_GET[] = {"s"};

#define GAM_ID       15             /* gamma / value */
#define GAM_NAME    'g'
ROM GAM_GET[] = {"g"};

#define REP_ID       17             /* repeat / value */
#define REP_NAME    'r'
ROM REP_GET[] = {"r"};

#define INF_ID       22             /* info button down */
#define SHF_ID       23             /* shift button down */
#define STP_ID       16             /* Stop button down */

// page 3 events
#define OKY_ID       7              /* okay button to exit this screen */
#define ADJ_ID       14             /* adjust button 10 bU up, 11 bL left, 12 bD down, 13 bR right */

#define XPO_ID       2              /* x position text */
#define XPO_NAME    'x'
ROM XPO_GET[] = {"n0"};     // get x position

#define YPO_ID       5              /* y position text */
#define YPO_NAME    'y'
ROM YPO_GET[] = {"n1"};             /* get y position */
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

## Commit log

2020-06-16 added eagle board files and libraries Use these to make your own arduinovisor boards
    [Adafruit PAM8302.brd, Adafruit PAM8302.sch, arduinoVisor.brd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]
2020-06-16 Added NBTV8-format WAV files. Put these on your MicroSD card plugged into the ArduinoVisor
    [config.txt]
2020-06-16 cleaned up reported errors in schematic, board prelude to rejigging power to KC version
2020-06-17 failed. lets try again
    [arduinoVisor.brd, arduinoVisor.sch]
2020-06-17 fixed 'repeat' and no-display autoplay
    [ArduinoVisor.cpp, televisor.h]
2020-06-18 board IR swap pins. ground planes. code uncrustified.
    [arduinoVisor.brd, arduinoVisor.sch]

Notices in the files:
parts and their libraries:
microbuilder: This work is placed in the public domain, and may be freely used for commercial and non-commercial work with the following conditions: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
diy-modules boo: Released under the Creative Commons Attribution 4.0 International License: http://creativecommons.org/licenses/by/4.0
